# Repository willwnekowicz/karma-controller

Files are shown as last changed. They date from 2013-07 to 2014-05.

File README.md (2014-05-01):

Karma Controller
================
A build-it-yourself 7-button USB controller for controlling Reddit.com through Reddit Enhancement Suite. Karma Controller lets you procrastinate on Reddit more productively. Its 7 buttons are used to up vote, down vote, select posts, toggle images, and open & close comment tabs.

More at http://karmacontroller.com/

The files here include a board layout and schematic, as well as the controller's arduino code.

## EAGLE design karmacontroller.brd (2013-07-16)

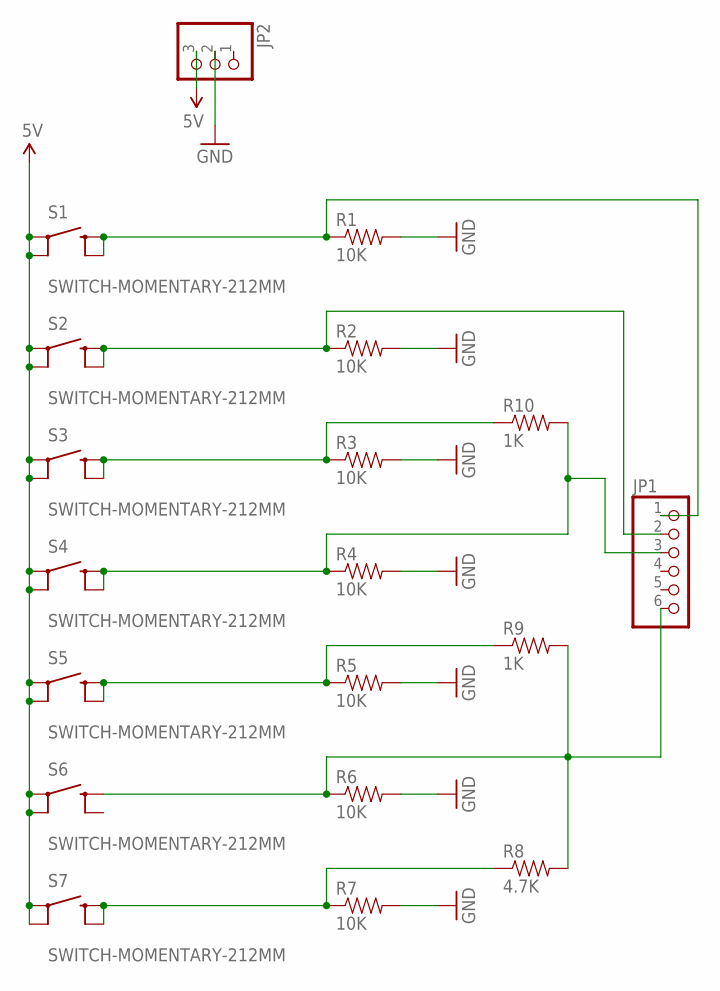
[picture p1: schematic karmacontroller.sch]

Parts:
JP1: PINHD-1X6; 1X06
JP2: PINHD-1X3; 1X03
R1, R2, R3, R4, R5, R6, R7: 10K; AXIAL-0.3
R8: 4.7K; AXIAL-0.3
R9, R10: 1K; AXIAL-0.3
S1, S2, S3, S4, S5, S6, S7: SWITCH-MOMENTARY-212MM; TACTILE-PTH-12MM

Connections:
5V: JP2.3, S1.1, S1.2 (1'), S2.1, S2.2 (1'), S3.1, S3.2 (1'), S4.1, S4.2 (1'), S5.1, S5.2 (1'), S6.1, S6.2 (1'), S7.1, S7.2 (1')
DOWN: R7.P$1 (1), R8.P$1 (1), S7.3 (2), S7.4 (2')
GND: JP2.2, R1.P$2 (2), R2.P$2 (2), R3.P$2 (2), R4.P$2 (2), R5.P$2 (2), R6.P$2 (2), R7.P$2 (2)
unnamed: JP1.2, R2.P$1 (1), S2.3 (2), S2.4 (2')
unnamed: JP1.1, R1.P$1 (1), S1.3 (2), S1.4 (2')
unnamed: JP1.3, R4.P$1 (1), R10.P$2 (2), S4.3 (2), S4.4 (2')
unnamed: R5.P$1 (1), R9.P$1 (1), S5.3 (2), S5.4 (2')
unnamed: JP1.6, R6.P$1 (1), R8.P$2 (2), R9.P$2 (2), S6.3 (2)
unnamed: R3.P$1 (1), R10.P$1 (1), S3.3 (2), S3.4 (2')

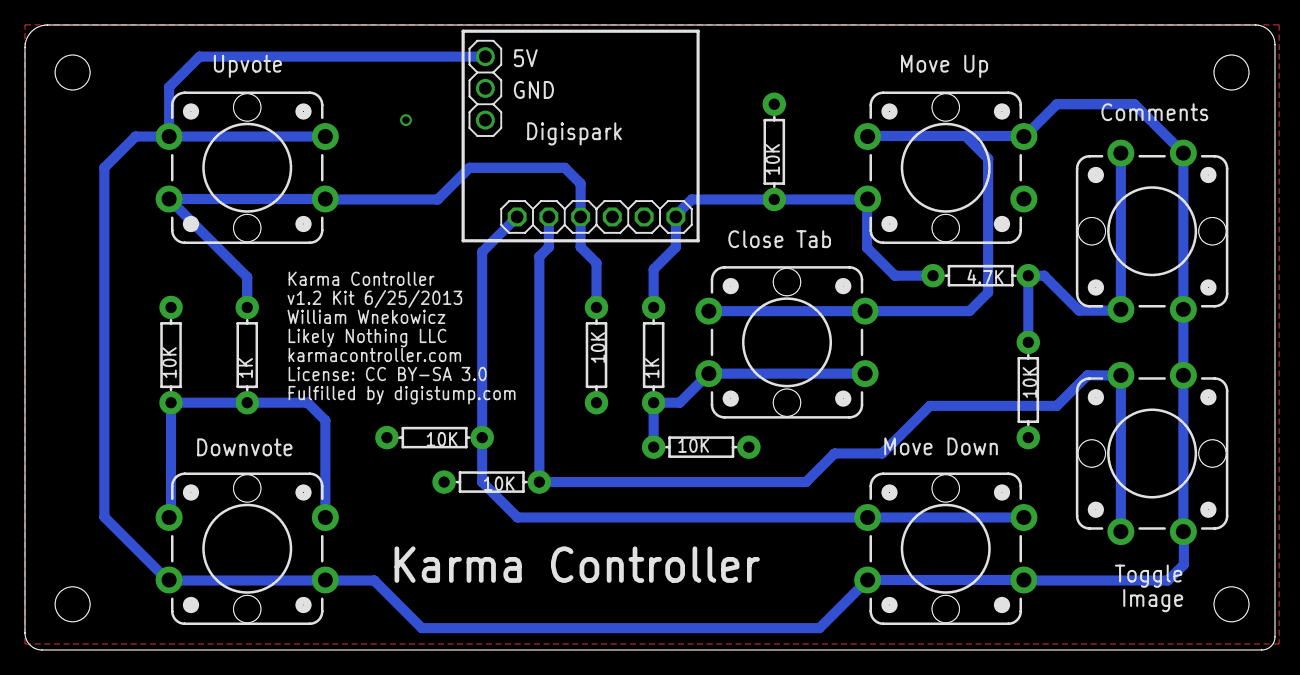
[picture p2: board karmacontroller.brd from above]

Board: 2 copper layers, 100.0 x 50.0 mm, 19 parts (0 on the bottom side), 9 nets.

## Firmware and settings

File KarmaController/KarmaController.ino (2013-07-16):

// v1.2
// Karma Controller by William Wnekowicz - Likely Nothing LLC
// This work is licensed under the Creative Commons Attribution-ShareAlike 3.0 Unported License. 
// To view a copy of this license, visit http://creativecommons.org/licenses/by-sa/3.0/.

#include "DigiKeyboard.h"

int lastReading0 = 0;
int lastReading1 = 0;
int lastReading2 = 0;
int lastReading5 = 0;

void setup() {      
  pinMode(0, INPUT); //button0 
  pinMode(1, INPUT); //button1
  pinMode(2, INPUT); //button2 & button3
  pinMode(5, INPUT); //button4 & button5 & button6
}

void loop() {
  int reading0 = digitalRead(0);
  int reading1 = digitalRead(1);
  int reading2 = analogRead(1);  
  int reading5 = analogRead(0);

  if(reading0 == HIGH && reading0 != lastReading0){
    DigiKeyboard.print("j");
  }

  if(reading1 == HIGH && reading1 != lastReading1){ 
    DigiKeyboard.print("x"); 
  }
  
  if((reading2 >= 1010 && reading2 <= 1024) && !(lastReading2 >= 1010 && lastReading2 <= 1024)){
    DigiKeyboard.print("a"); 
  }
  
  if((reading2 >= 920 && reading2 <= 940) && !(lastReading2 >= 920 && lastReading2 <= 940)){
    DigiKeyboard.print("z"); 
  }
  
  if((reading5 >= 532 && reading5 <= 546) && !(lastReading5 >= 532 && lastReading5 <= 546)){
    DigiKeyboard.print("C");
  }
  
  if((reading5 >= 865 && reading5 <= 885) && !(lastReading5 >= 865 && lastReading5 <= 885)){
    DigiKeyboard.sendKeyStroke(KEY_W,MOD_GUI_LEFT); 
  }
  
  if((reading5 >= 1010 && reading5 <= 1024) && !(lastReading5 >= 1010 && lastReading5 <= 1024)){

    DigiKeyboard.print("k"); 
  }
  
  lastReading0 = reading0; 
  lastReading1 = reading1;
  lastReading2 = reading2;  
  lastReading5 = reading5; 
  
  DigiKeyboard.delay(1);
}

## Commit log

2013-04-16 Karma Controller v1.0 Initial Commit
    [karmacontroller.brd, karmacontroller.sch]
2013-04-18 v1.1 for first production PCB print
    [karmacontroller.brd, karmacontroller.sch]
2013-04-18 Added DigiSpark Arduino code
2013-05-29 Prepared for fabrication (v1.1)
    [karmacontroller.brd]
2013-07-16 Upgraded board and software
    - I changed all the resistors to the Sparkfun AXIAL-0.3 and rerouted
    everything.
    - I changed the mask limit to 25mil.
    - I moved the "Karma Controller" text over to the left.
    - I hid the tOrigins layer. These are the crosshairs.
    - I updated the date to 6/25/2013
    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
    [karmacontroller.brd, karmacontroller.sch]

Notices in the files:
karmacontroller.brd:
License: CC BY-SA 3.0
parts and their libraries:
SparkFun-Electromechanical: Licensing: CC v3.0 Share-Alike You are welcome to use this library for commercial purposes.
